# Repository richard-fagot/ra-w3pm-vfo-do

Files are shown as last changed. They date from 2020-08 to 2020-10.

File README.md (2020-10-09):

**TODO : Ajouter le sketch de l'arduino pour être sûr qu'il soit disponible.**
# Oscillateur à fréquence variable asservi par GPS de 1 à 112,5MHz
Ultra précis (0.1Hz avec le module GPS) cet oscillateur à signaux carrés programmable dispose de deux sorties d'horloge.

Ce projet propose un PCB compact, s'enfichant à l'arrière du LCD et supportant le l'oscillateur SI5351. **TODO : Le GPS est relié par des câbles ?**.

Ce PCB repose sur le [schéma créé par W3PM](http://www.knology.net/~gmarcus/Si5351/Si5351_VFO_QEX.pdf) (voir la [page de l'auteur](http://www.knology.net/~gmarcus/)).

# Réalisation

Après avoir fait réaliser le PCB, souder les composants dans cet ordre :

## Alimentation
Souder les composants dans cet ordre :
- C3, C4, C5 et C6 ;
- D1 ;
- U1 (utiliser une panne plate et large pour le GND).

Vérifier que l'alimenation de la carte est correctement régulée en appliquant une tension d'au moins 10V au niveau de l'emplacement du connecteur J9. La tension mesurée au pin *+5V* à l'emplacement du connecteur GPS doit être de 5V.

Si ce n'est pas le cas, mesurer la tension entre la sortie de U1 et sa patte dissipateur/GND :
- Si elle est différente de 5V c'est qu'au moins un des condensateurs C3, C4, C5 ou C6 est défectueux ou de mauvaise valeur ;
- Si elle vaut 5V c'est que la soudure du GND n'est pas correctement réalisée.

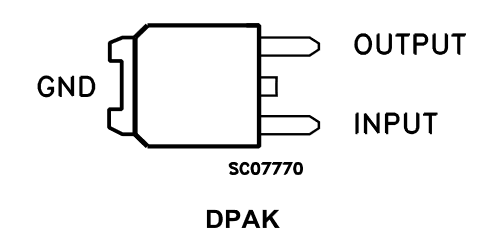
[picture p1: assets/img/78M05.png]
78M05


Éviter de souder l'arduino directement, utiliser plutôt des connecteurs.

# BOM

L'ensemble des composants coûte environ 30€ hors boitier et PCB.

| Référence | Quantité | Valeur | Source | Prix |
|----|-----|-----|-----|-----|
| C1, C2, C4, C5 | 4 | 0.1µF boitier CMS 0805 || 0,04€ |
| C3, C6 | 2 | 4.7µF boitier CMS 0805 || 0,02€ |
| J2, J3, J4, J9 | 4 | Connecteur dupont mâle vertical 1x2 broches pas 2,54 mm || 0,04€ |
| J1 | 1 | Connecteur dupont mâle vertical 1x3 broches pas 2,54 mm || - |
| J5 | 1 | Connecteur dupont femelle vertical 1x7 broches pas 2,54 mm || 1,00€ |
| J10 | 1 | Connecteur dupont femelle vertical 1x4 broches pas 2,54 mm || 1,00€ |
| J8 | 1 | Connecteur dupont femelle vertical 1x16 broches pas 2,54 mm || 1,00€ |
| D1 | 1 | Diode schottky boitier CMS SS24 || 0,0299€ |
| U1 | 1 | Régulateur linéaire L78M05 boitier CMS TO-252 || 0,189€|
| RV1, RV2 | 1 | potentiomètre 10k boitier CMS 3x3 || 0,216€ |
| A1 | 1 | Arduino nano v3.0|| 1,70€|
| LCD | 1 | Écran LCD 16x2 à controlleur HD44780 || 5,00€ |
| SI5351 | 1 | Module SI5351 à 7 broches || 6,00€ |
| GPS | 1 | Module GPS avec antenne || 15,00€ |
| Boutons poussoir | 3 ||| 1,50€ |
| Encodeur rotatif | 1 | Encodeur rotatif avec son bouton || 0,50€ |
| Coaxial | qsp | Câble coaxial RG316 || 0,50€|
| Boitier |||||

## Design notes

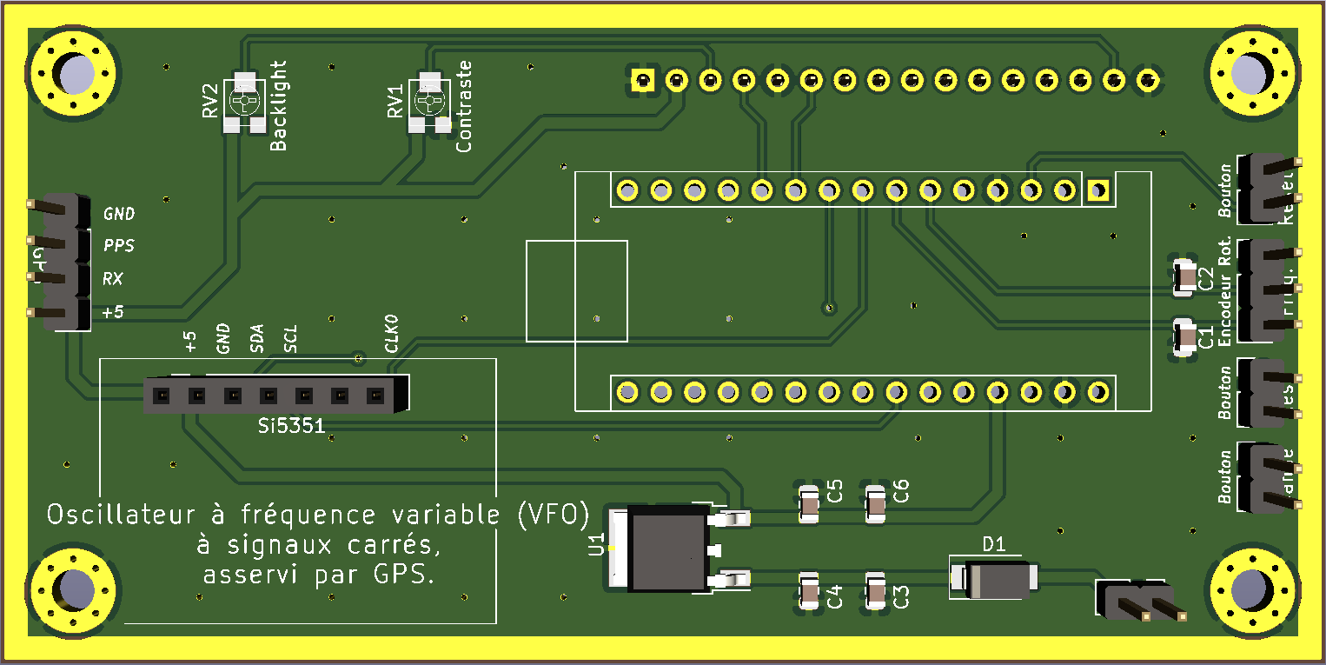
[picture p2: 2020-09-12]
assets/img/front.png

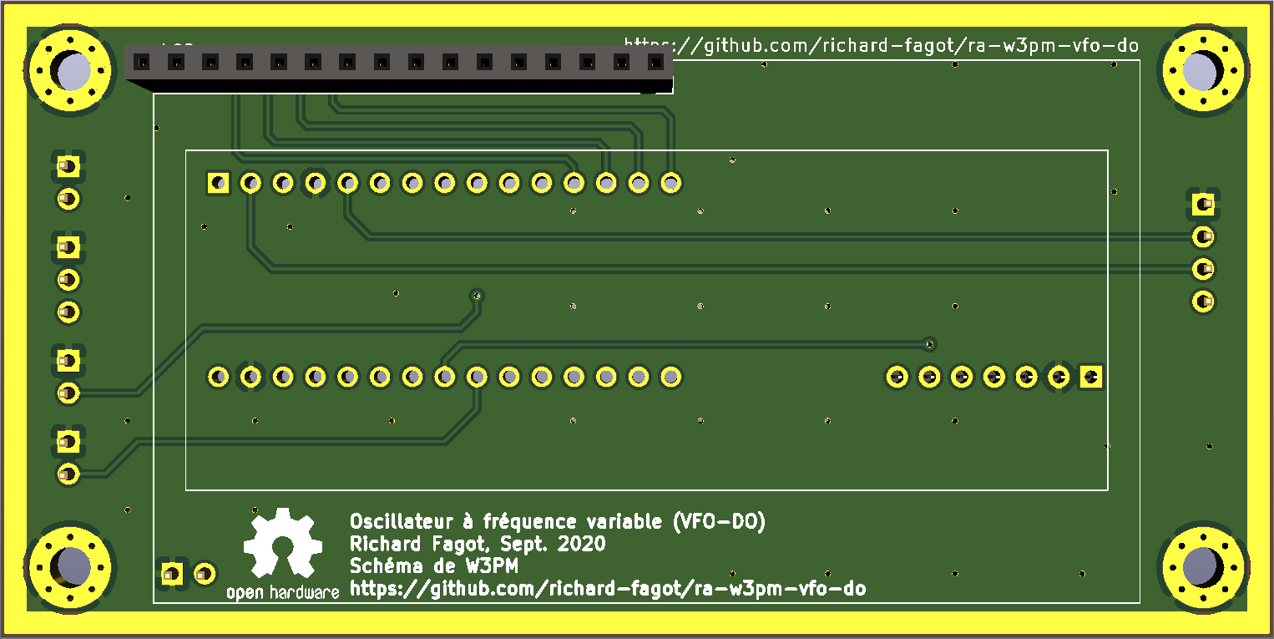
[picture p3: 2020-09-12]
assets/img/back.png

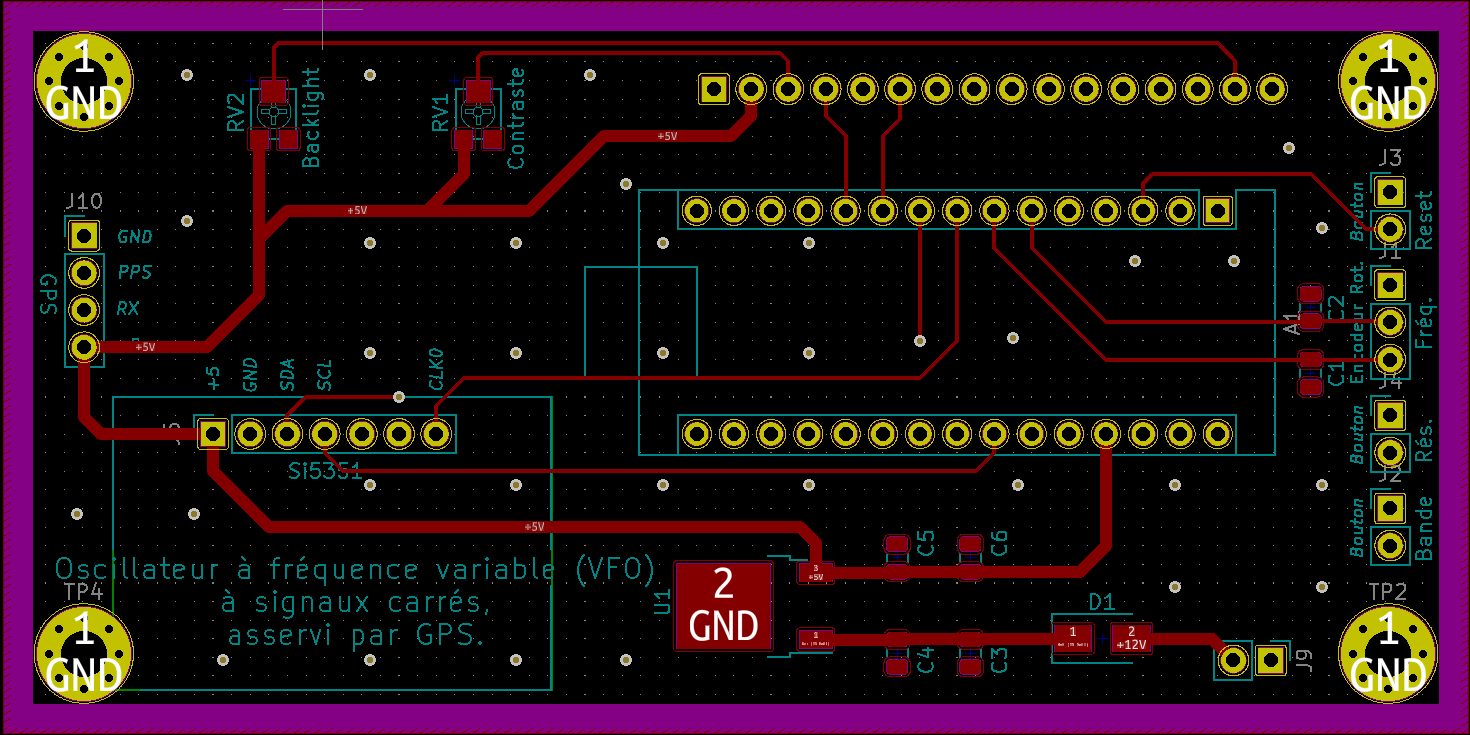
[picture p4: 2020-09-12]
assets/img/pcb_front.png

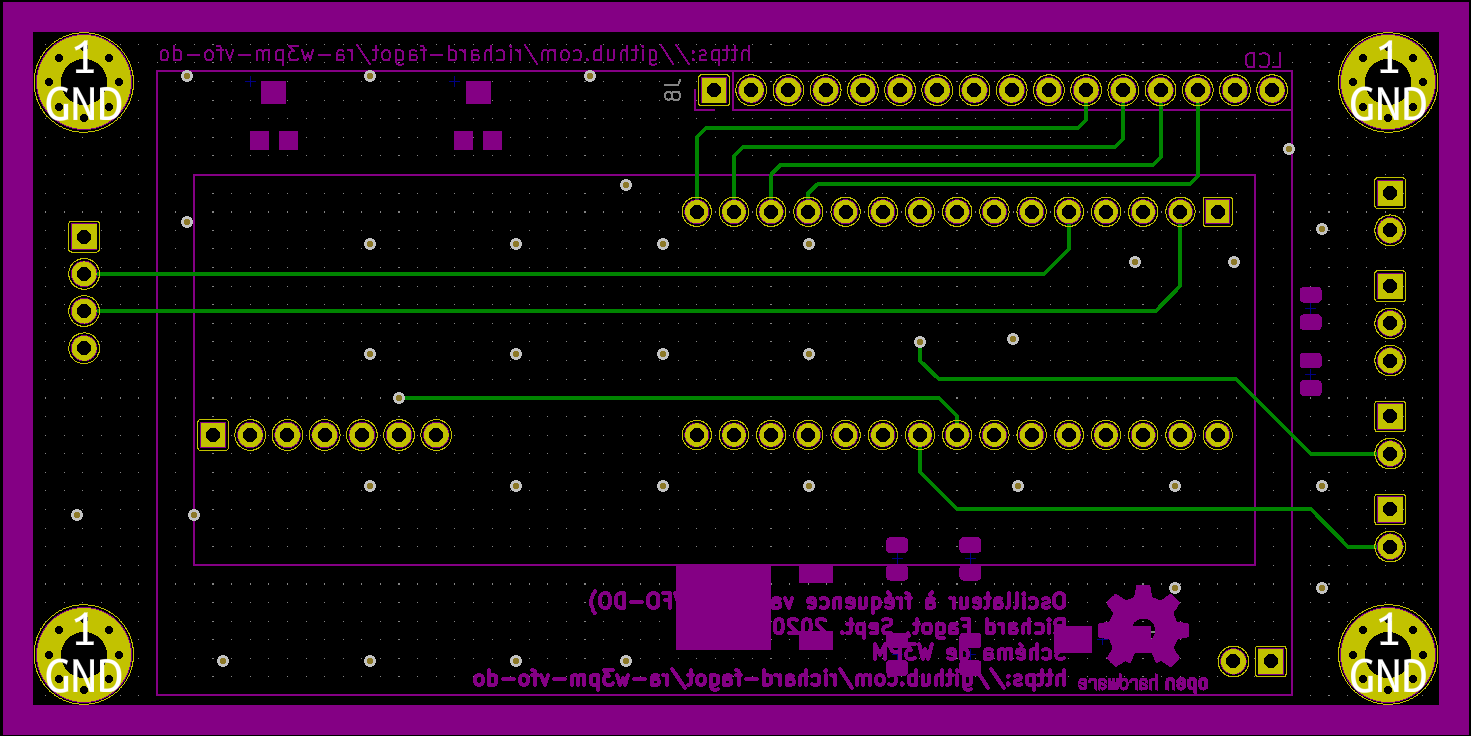
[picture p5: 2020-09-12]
assets/img/pcb_back.png

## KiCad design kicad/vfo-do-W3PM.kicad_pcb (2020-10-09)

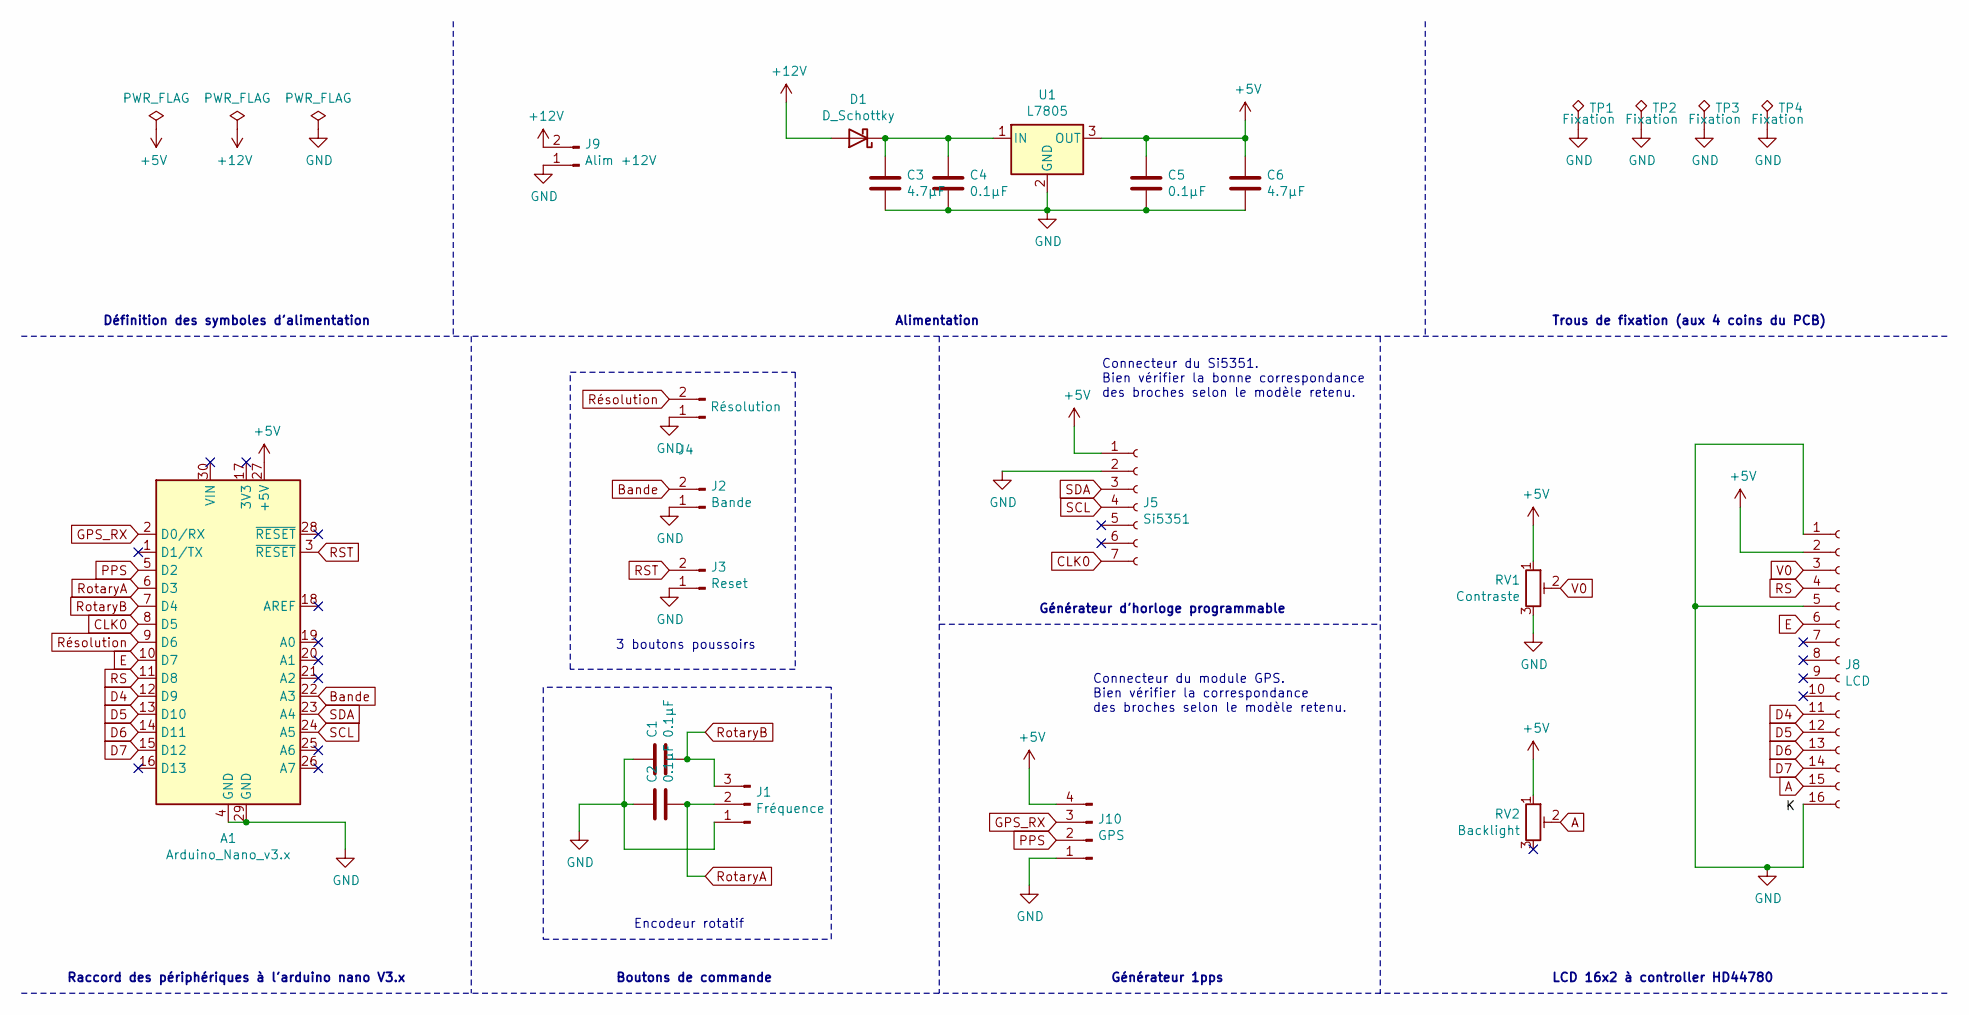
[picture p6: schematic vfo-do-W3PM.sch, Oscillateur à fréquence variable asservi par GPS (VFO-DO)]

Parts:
A1: Arduino_Nano_v3.x; Arduino_Nano
C1, C2, C4, C5: 0.1µF; C_0805_2012Metric
C3, C6: 4.7µF; C_0805_2012Metric
D1: D_Schottky; D_SMA
J1: Fréquence; PinHeader_1x03_P2.54mm_Vertical
J2: Bande; PinHeader_1x02_P2.54mm_Vertical
J3: Reset; PinHeader_1x02_P2.54mm_Vertical
J4: Résolution; PinHeader_1x02_P2.54mm_Vertical
J5: Si5351; PinSocket_1x07_P2.54mm_Vertical
J8: LCD; PinSocket_1x16_P2.54mm_Vertical
J9: Alim +12V; PinHeader_1x02_P2.54mm_Vertical
J10: GPS; PinHeader_1x04_P2.54mm_Vertical
RV1: Contraste; trimmer_3x3
RV2: Backlight; trimmer_3x3
TP1, TP2, TP3, TP4: Fixation; MountingHole_3.2mm_M3_Pad_Via
U1: L7805; TO-252-2

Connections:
+5V: A1.27 (+5V), C5.1, C6.1, J5.1, J8.2, J10.4, RV1.1, RV2.1, U1.3 (OUT)
+12V: D1.2 (A), J9.2
A: J8.15, RV2.2
Bande: A1.22 (A3), J2.2
CLK0: A1.8 (D5), J5.7
D4: A1.12 (D9), J8.11
D5: A1.13 (D10), J8.12
D6: A1.14 (D11), J8.13
D7: A1.15 (D12), J8.14
E: A1.10 (D7), J8.6
GND: A1.4 (GND), A1.29 (GND), C1.1, C2.1, C3.2, C4.2, C5.2, C6.2, J1.1, J2.1, J3.1, J4.1, J5.2, J8.1, J8.5, J8.16, J9.1, J10.1, RV1.3, TP1.1, TP2.1, TP3.1, TP4.1, U1.2 (GND)
GPS_RX: A1.2 (D0/RX), J10.3
unnamed: C3.1, C4.1, D1.1 (K), U1.1 (IN)
PPS: A1.5 (D2), J10.2
RS: A1.11 (D8), J8.4
RST: A1.3 (~RESET), J3.2
RotaryA: A1.6 (D3), C2.2, J1.2
RotaryB: A1.7 (D4), C1.2, J1.3
Résolution: A1.9 (D6), J4.2
SCL: A1.24 (A5), J5.4
SDA: A1.23 (A4), J5.3
V0: J8.3, RV1.2

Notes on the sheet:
Définition des symboles d'alimentation
Alimentation
Trous de fixation (aux 4 coins du PCB)
3 boutons poussoirs
Encodeur rotatif
Boutons de commande
Connecteur du Si5351. Bien vérifier la bonne correspondance des broches selon le modèle retenu.
Connecteur du module GPS. Bien vérifier la correspondance des broches selon le modèle retenu.
Générateur d'horloge programmable
Générateur 1pps
LCD 16x2 à controller HD44780
Raccord des périphériques à l'arduino nano V3.x

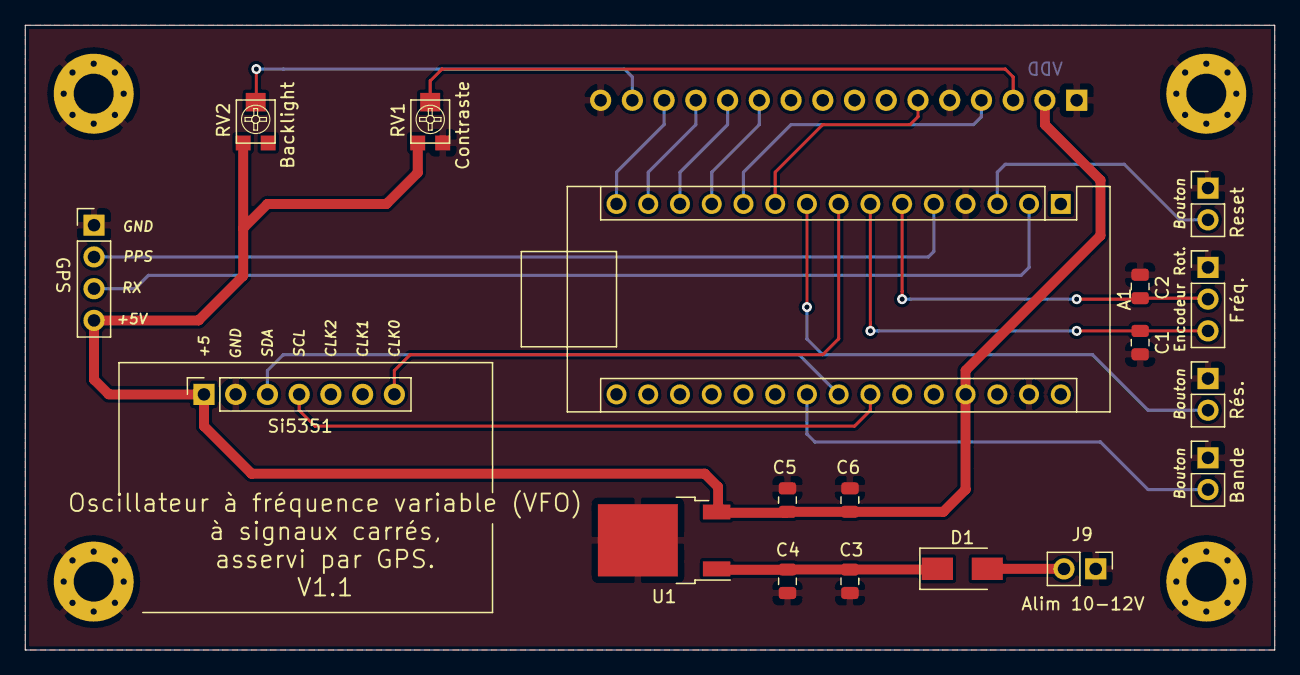
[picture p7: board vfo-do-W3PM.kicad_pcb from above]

Board: 2 copper layers, 100.0 x 50.0 mm, 23 parts (1 on the bottom side), 22 nets.

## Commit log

2020-08-23 Nouveau design PCB avec les conseils du discord
    [vfo-do-with-trimmer.kicad_pcb, vfo-do-with-trimmer.sch, vfo-do-with-trimmer_boutons regroupés.kicad_pcb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]
2020-08-24 Amélioration du routage, perçage de fixation
    [vfo-do-with-trimmer_boutons regroupés.kicad_pcb]
2020-08-25 plaque standard 10x5
    [vfo-do-with-trimmer.kicad_pcb, vfo-do-with-trimmer.sch, vfo-do-with-trimmer_boutons regroupés-10x5.kicad_pcb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]
2020-09-11 Ajout des bonnes empreintes pour les trimmers
    [vfo-do-with-trimmer.sch, vfo-do-with-trimmer_boutons regroupés-10x5.kicad_pcb]
2020-09-12 Réorganisation du projet + début doc
    [vfo-do-W3PM.kicad_pcb, vfo-do-W3PM.sch, vfo-do-with-trimmer.kicad_pcb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]
2020-10-09 Fix sens connecteur LCD
    [vfo-do-10x5-B_Cu.gbr, vfo-do-10x5-B_Mask.gbr, vfo-do-10x5-B_SilkS.gbr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]
